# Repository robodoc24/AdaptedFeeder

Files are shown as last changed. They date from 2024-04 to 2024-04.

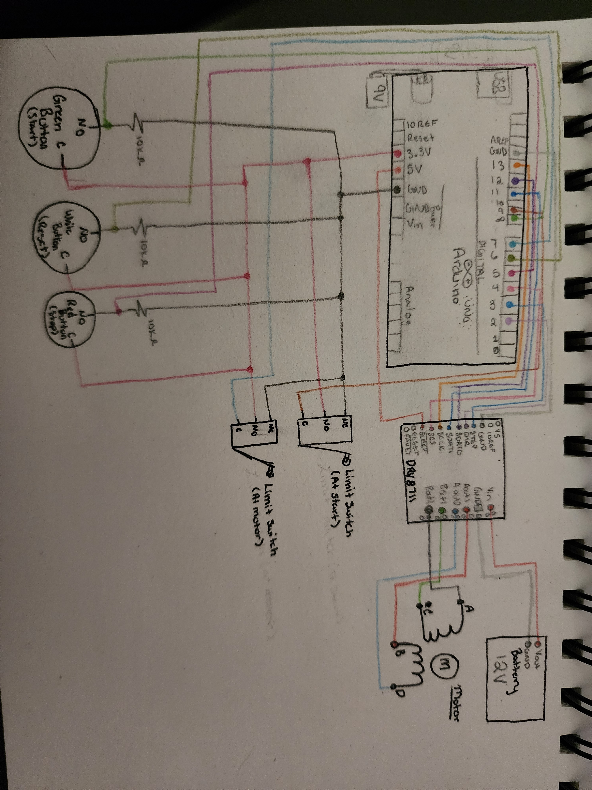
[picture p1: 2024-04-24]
CircuitLayedOut.jpg

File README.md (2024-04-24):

# AdaptedFeeder
The Adapter Feeder is a medical device that is designed to empower individuals facing disabilities such as uncontrollable limb spasms or weakness in the arms, which can hinder independent feeding. This medical device provides essential support by enabling individuals with disabilities to self-feed, reducing their dependence on others. 

Read the user manual for instruction.
There is also a trouble shooting guide in the User Manual.

All files needed to create the device are uploaded here.

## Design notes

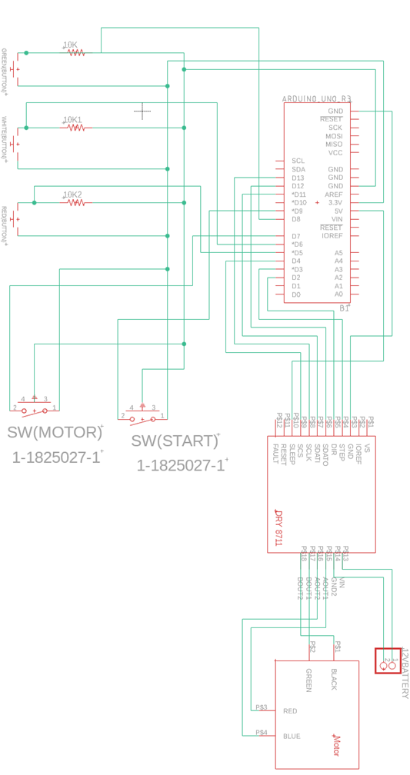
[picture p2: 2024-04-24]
Fusion.png

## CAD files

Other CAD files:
Adaptive Feeder v5.f3z

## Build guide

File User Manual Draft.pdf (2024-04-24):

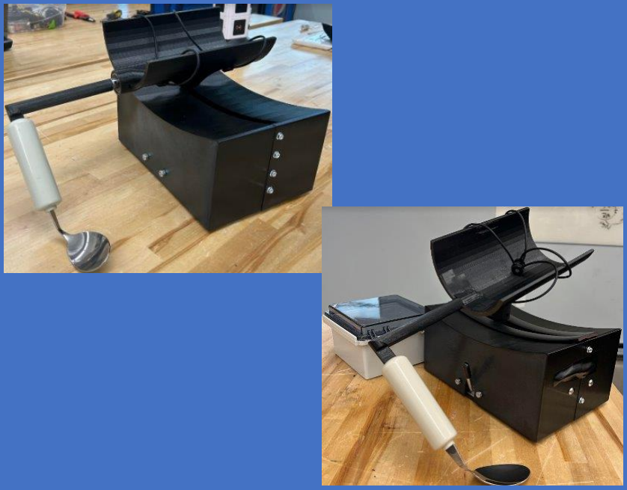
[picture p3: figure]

# ADAPTIVE FEEDER

Our adaptive feeder: a tool for independence, dignity, and empowerment. Let's redefine possibility, one invention at a time.

Grand Canyon
University Capstone

## Table of Contents

# Introduction

## The Adaptive Feeder is a device used to empower individuals with

## disabilities to gain independence in feeding themselves. With its

## intuitive design and helpful features, it serves as a reliable guide to

support users in mastering the art of self-feeding.

# Overview

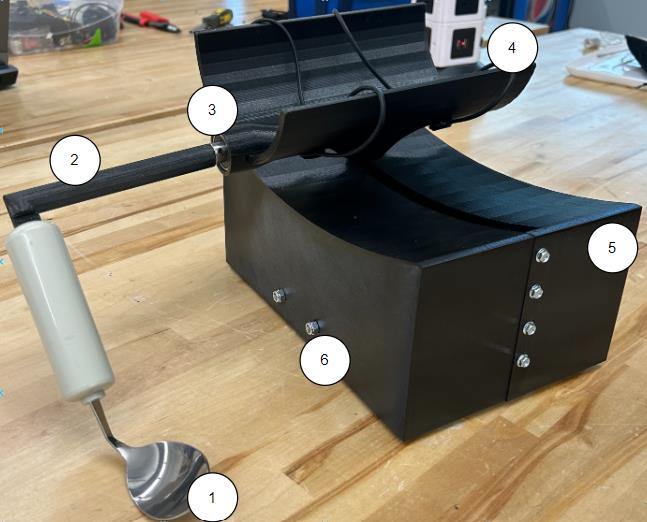
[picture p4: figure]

1. Spoon | 3. Bearing
2. Handlebar | 4. Arm Holder
5. Base | 6. Panavise (Inside Base)

# Materials list

Materials Needed | Quantity | Cost Total ($) | Vendor & Link
Lead Screw and Brass Nut | 1 | $26.97 | Amazon (https://www.amazon.com/QWORK-300mm-Thread-Starts-Printer/dp/B0C2VLY8VH?s=industrial)
Pololu High-Power Stepper Motor Driver 36v4 | 1 | $24.00 | Pololu (https://www.pololu.com/product/3730)
Stepper Motor: Bipolar, 200 Steps/Rev, 57×76mm, 3.2V, 2.8 A/Phase | 1 | $73.37 | Pololu (https://www.pololu.com/product/1478/pictures)
Motor Shaft Coupler | 2 | $12.99 | Amazon (https://www.amazon.com/6-35mm-8mm-Flexible-Coupling-6-35x8mm/dp/B00V84QS2Q?s=hi)
KBT 12V 2400mAh Rechargeable Li-ion Battery | 2 | $22.99 | Amazon (https://www.amazon.com/KBT-2400mAh-Rechargeable-Replacement-Compatible/dp/B0C241NS29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)
9V Battery | 1 | $7.10 | Amazon (https://www.amazon.com/Energizer-Alkaline-General-Purpose-Battery/dp/B00003IE4E)
Certified Food Grade PETG 3D Printer Filament Roll | 2 | $41.61 | Amazon (https://www.amazon.com/Certified-Food-Grade-Printer-Filament/dp/B0BTLNRRN4)
ELEGOO UNO Project Super Starter | 1 | $38.80 | Amazon (https://www.amazon.com/ELEGOO-Project-Tutorial-Controller-Projects/dp/B01D8KOZF4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)
Self-Alignment Bearing | 1 | $9.69 | Amazon (https://www.amazon.com/TAODAN-Silver-Pillow-Bearing-Self-Alignment/dp/B0CHYDYWSP?hvadid=675616684759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)
Adaptive Spoon | 1 | $6.95 | Amazon (https://www.amazon.com/Rehabilitation-Advantage-Teaspoon-Adaptive-Built-up/dp/B07BXFJ8ZV)
Vive Foam Tubing | 1 | $16.14 | Amazon (https://www.amazon.com/Vive-Foam-Tubing-Pack-Dexterity/dp/B01MXVPY53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)
PANAVISE 380 Vacuum Base | 1 | $61.42 | Amazon (https://www.amazon.com/Panavise-8106-PanaVise-Vacuum-Base/dp/B0002BC294?hvadid=312381485501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)
12 Pack 8/32 Inch M4 Threaded Rod with Hex Nuts 12 Pcs M4 Stainless Steel Threads Studs Rods 12 Pcs M4 Stainless Steel Fully Threaded Hex Nuts for Beaded Garden Stake Rods (8 Inch) | 1 | $10.76 | Amazon (https://www.amazon.com/gp/aw/d/B0BLSJX1KX/?aaxitk=236423587a5ec7b18561ca52c3eb3b81&hsa_cr_id=0)
Push Buttons | 3 | $18.88 | Amazon (https://www.amazon.com/dp/B01MSNXLN0?psc=1&ref=ppx_yo2ov_dt_b_product_details)
Limit Switches | 2 | $5.99 | Amazon (https://www.amazon.com/HiLetgo-KW12-3-Roller-Switch-Normally/dp/B07X142VGC?sp_csd=d2lkZ2V0TmFtZT1zcF9hdGY)
Rubber Stripping Roll | 1 | $13.99 | Amazon (https://www.amazon.com/s?k=rubber+striping)
Electrical Waterproof Box | 1 | $20.99 | Amazon (https://www.amazon.com/dp/B0CHHJ49QN?ref=ppx_yo2ov_dt_b_product_details&th=1)
Self-Tapping Hex Screws Pack | 1 | $9.99 | Amazon (https://www.amazon.com/Available-Washer-Drilling-Tapping-Stainless/dp/B08HSTSLQ4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)
Wire Nuts Pack | 1 | $8.97 | Amazon (https://www.amazon.com/Electrical-Wire-Connectors-Screw-Terminals/dp/B082KMK6Y9?sp_csd=d2lkZ2V0TmFtZT1zcF9hdGY)
Magnet Straps | 4 | $14.99 | Amazon (https://www.amazon.com/Magnetic-Organizer-FGSAEOR-Management-Organizing/dp/B0B2DTD4QK)
Speaker Wire Spool | 1 | $8.99 | Amazon (https://www.amazon.com/InstallGear-Gauge-30ft-Speaker-Cable/dp/B078YYXDWP)
Electrical Tape | 1 | $4.98 | Amazon (https://www.amazon.com/Scotch-Super-33-Electrical-carton/dp/B0000AZ9HG)
Total (Electric) | | $460.56
Total (Mechanical-Underlined) | | $155.86

# Health and Safety

## - Make sure to read all the instructions before building the device and make sure to use the CAD/code files attached in the links section. If done incorrectly the device may not work

properly and could cause harm.

## - The adaptive feeder should not be used without someone

supervising in case of choking or something going wrong.

## - People with uncontrolled movements should not use metal

spoons on the device, instead use plastic ones.
- Make sure to not run device if a wire is exposed.
- Make sure to have a fully or half charged battery.

## - Do not touch any exposed electrical components when the

power is on.

## - Before use make sure the base is fully secured to the table with the Pana-Vise - Ensure the device was reassembled correctly and nothing is to

lose.

## - Do a routine check up on all components every two or three

weeks.
- Make sure to wipe and clean all parts before every meal.

# Adaptations

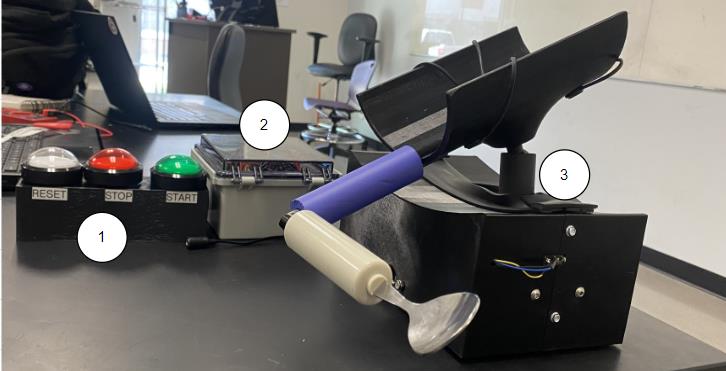
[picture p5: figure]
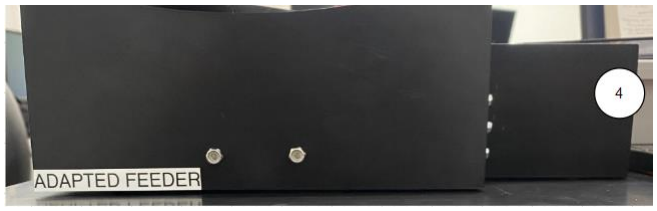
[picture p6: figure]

## 1. A button box with buttons can be added to make the motorized version of this device 2. An electrical box needs to be added to maintain all the wires

safe for the motorized version.

## 3. The joint can at the spoon holder can be removed and a joint can be added on the base for the motorized version 4. The motor and screw rod can be removed and the adaptive

could be used mechanically.

## 5. The motor and screw rod can be removed and the adaptive

could be used mechanically.

## 6. The motor case needs to be added to keep the motor safe from

any food and make it the motorized version.

# Quick Set up with motor

1.

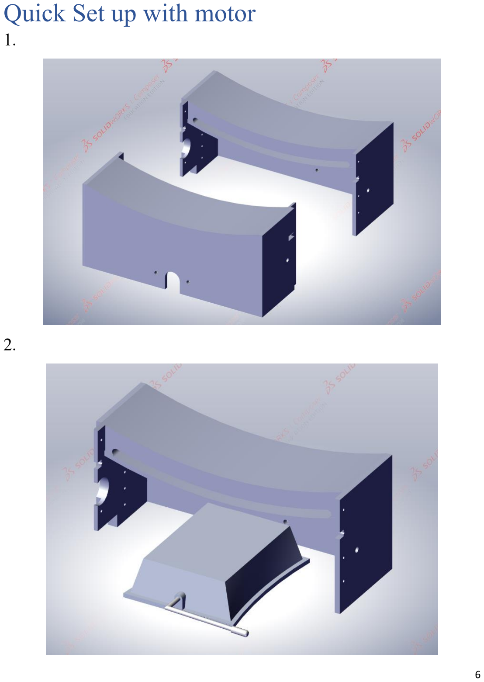
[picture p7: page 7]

2.

3

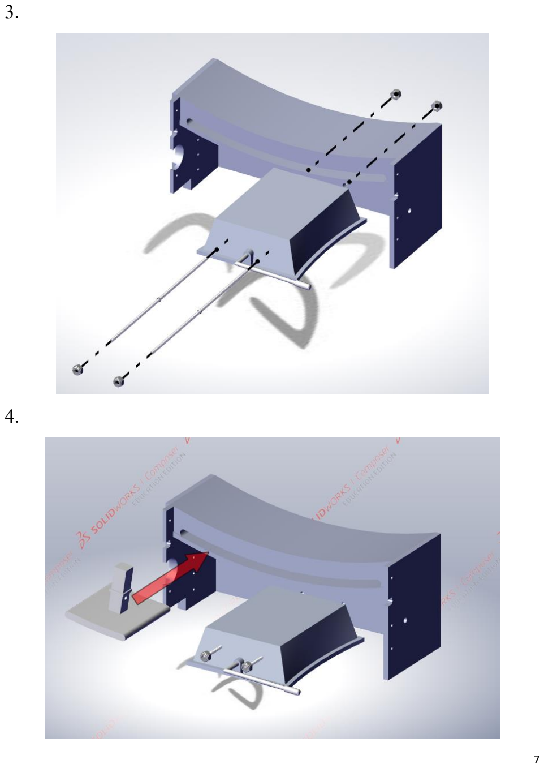
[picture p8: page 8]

4.

5.

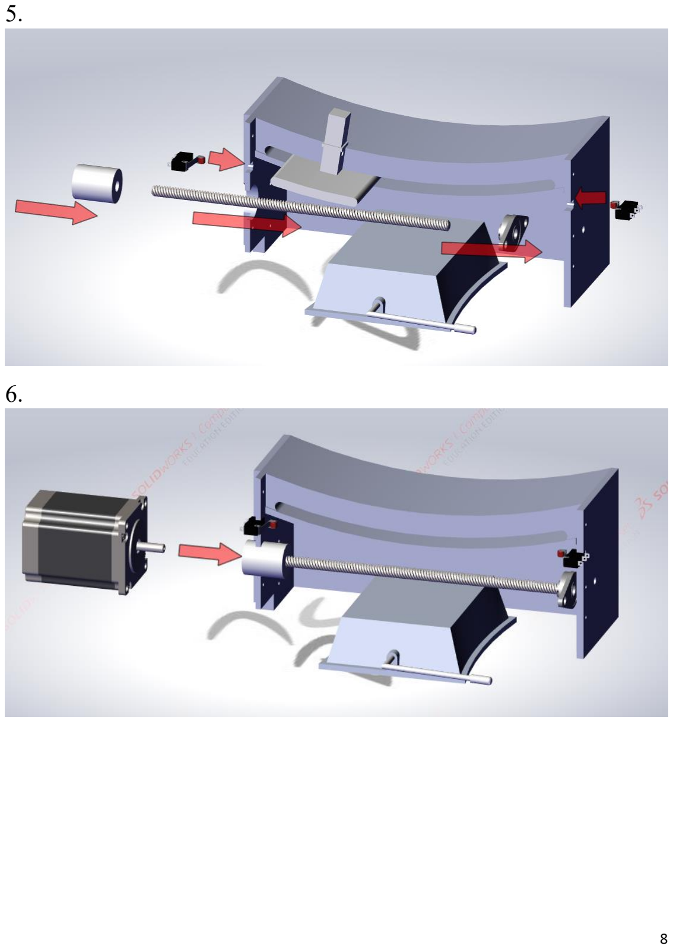
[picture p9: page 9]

6.

7.

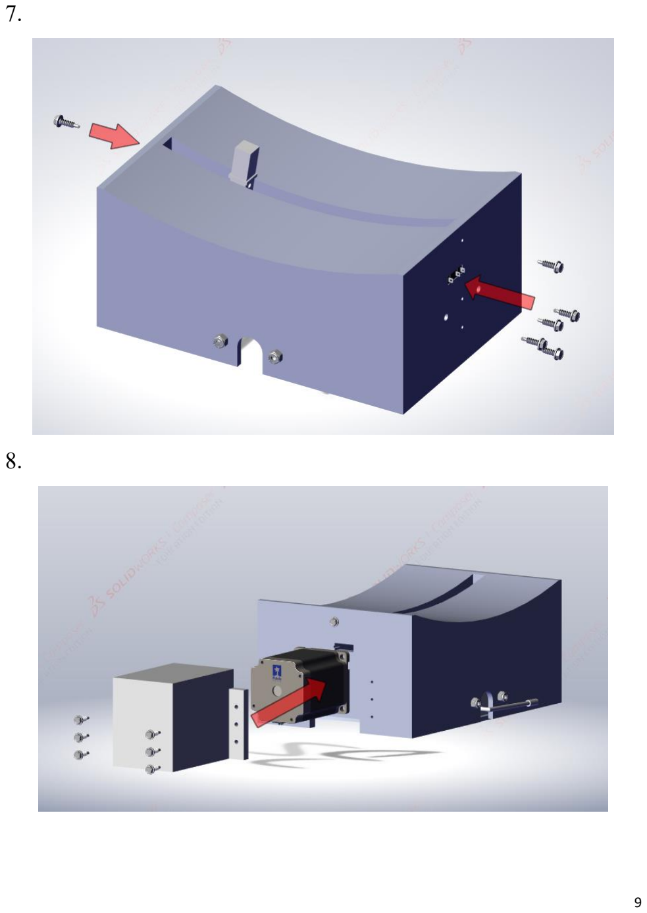
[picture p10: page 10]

8.

9.

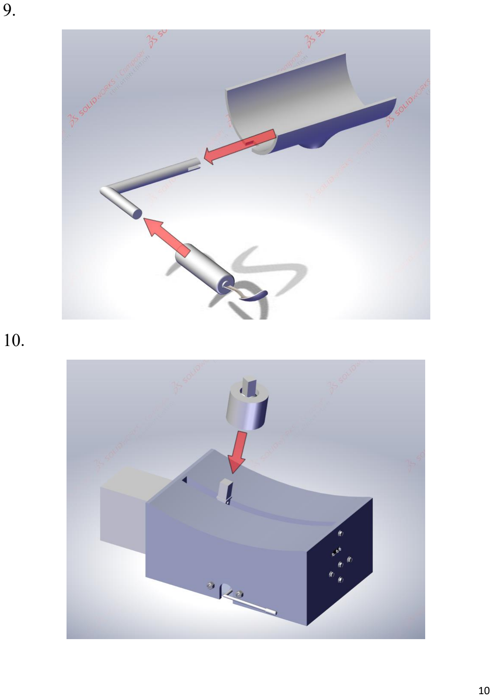
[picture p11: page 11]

10.

11.

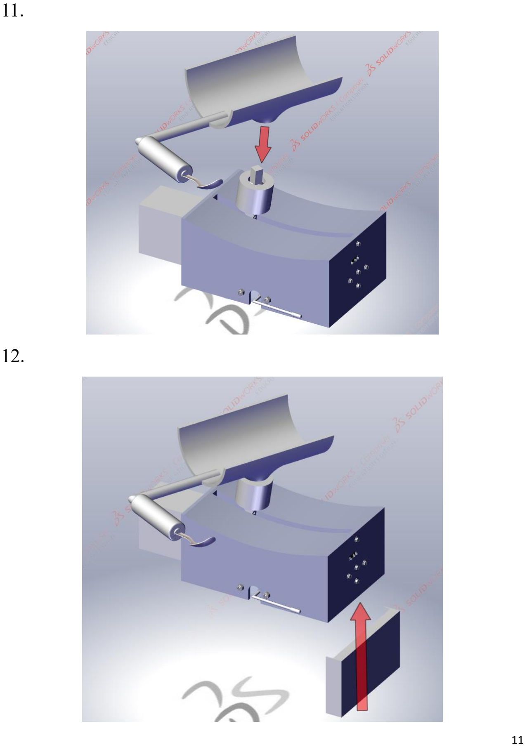
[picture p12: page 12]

12.

13.

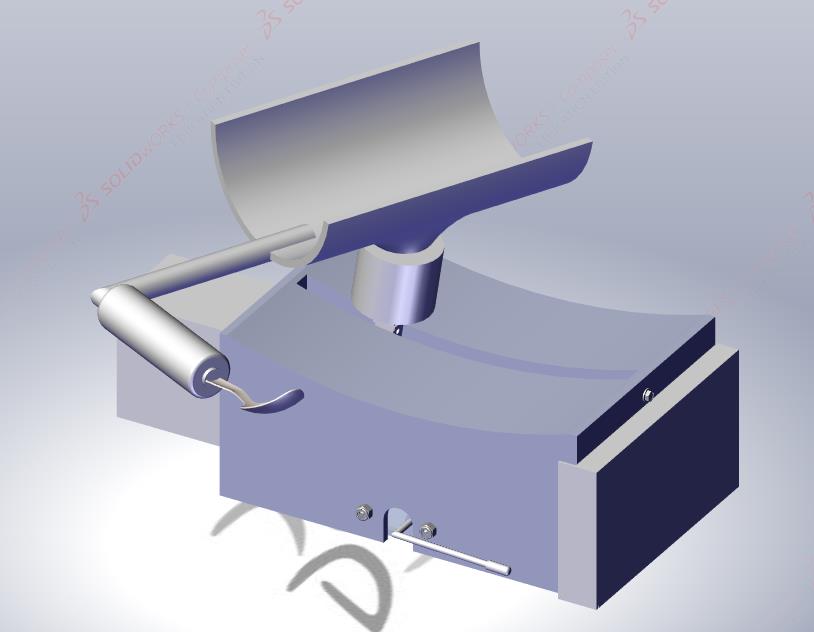
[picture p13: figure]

# Quick Set Up Without Motor

## Reference these steps 1, 2, 3, 4, 7, 9, 10 and 11 from Quick Motor

Set Up.

# Electrical Diagram how to build

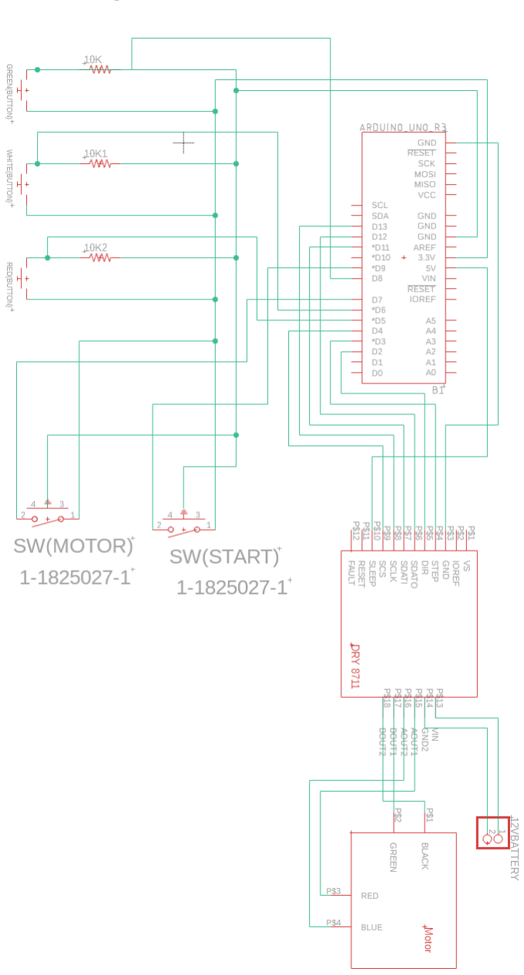
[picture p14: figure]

# How to assemble

## Mechanical Design: Assemble into 3 pieces Place part 3 on part 1 at the flat surface. Then place part 1 on part 4 the slider. To add more support to the handle on part 1 add part 2 to

the area with the round surface.

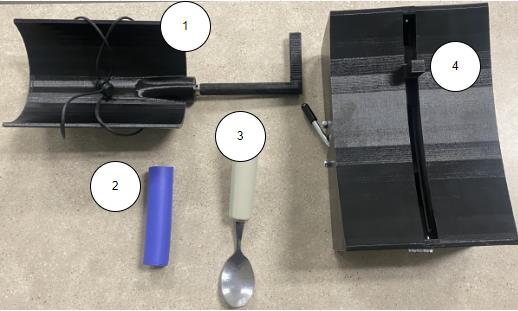
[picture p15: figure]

## For further detail watch the YouTube video called “Mechanical Assemble”

## Motorized Design: Assemble into 3 pieces Place part 2 on part 4 where the square indent is. Place part 1 on part two where there is a flat surface. Then place all parts onto part 1 the base on part 5. To add a better grip place part three on part 2 around

the round part.

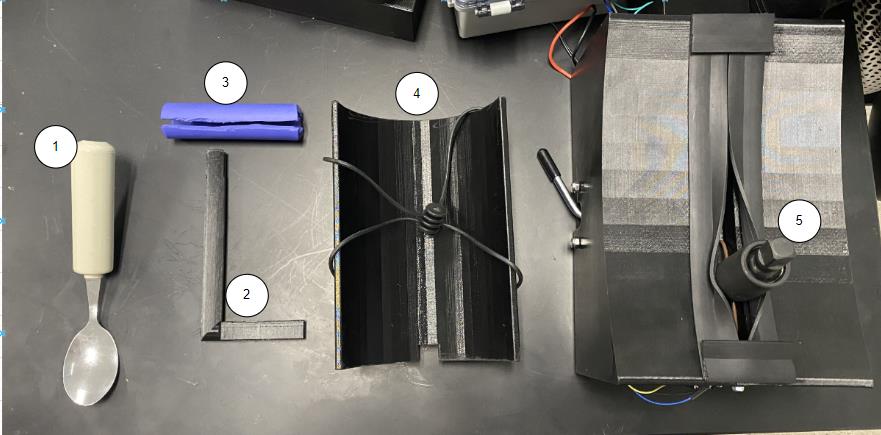
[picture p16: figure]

## For further detail watch the YouTube video called “Motorized Assembled”

# How to dissemble for easy storage

## Mechanical Desing: Disassemble into 3 pieces

## Remove part 1 from part 4 the slider. Then remove part 3 and 2 for

easier storage and cleaning.

## For further detail watch the YouTube video called “Mechanical Disassemble”

## Motorized Design: Disassemble into 5 pieces

## Remove part 1 by pulling it off part two. Next pull part 2 from part

4 and remove part 3. Once the smaller compartments are off,

## remove the arm holder part 4 from part 5. Removing all parts creates easier access to clean and store. Everything now can be stored in a

cabinet.

## For further detail watch the YouTube video called “Motorized Disassemble”

# Maintenance and Cleaning

## How to clean spoon Remove the spoon from the adaptive feeder by pulling it off. Put

spoon on the dishwasher or clean by hand with soap and water.

## How to clean the arm support To clean the arm support remove it from the base by the ball joint

and use soap and water to clean.

## How to clean the base and other components To clean the outside of the base, use a wet towel with disinfectant spray. If food falls inside the track, make sure to take apart the base by removing the screws and wiping the inside down. Make sure to

also wipe down the lead screw.

## How to prevent the lead screw from rusting To help the lead screw last longer grease can be applied. Add a bit of grease on the lead screw and run the motor to ensure the entire lead screw is covered. Lightly remove extra grease if any. If the lead

screw needs cleaning reapply grease.

## How to clean electrical components

Do not use any disinfectant or water to clean electrical components.

## Use a dry paper towel and wipe the electronic parts. If it is wet do not turn it on until it is completely dry. Make sure to test the adaptive feeder on its own first to make sure everything works

correctly. If everything moves correctly it can be used as normal.

## Chip and motor regular checkup

Check the wires for any pinching or the soldering for dulling, rough,

## or cracking in appearance to ensure the soldering of the electrical

components are still at max efficiency.

# Trouble Shooting

Problem | Possible Problem | Solution | Did it fix the problem?
For any problem start at the code, its designed to help isolate a problem. | Have the serial monitor open connected to the Arduino. | Read the serial motor for hits on any buttons that are not working and follow comments for helpful hints. | YES/NO
Not moving and no sound | A wire may have come undone | Check Wires | YES/NO
| Is it on? | Turn on power | YES/NO
Moved but stopped at motor (after hitting green button) | Did the power get turned off? | Turn on the power | YES/NO
| Are any wires loose? | Check wires plug in any loose wires | YES/NO
Started to move and stopped or not moving with a grinding sound | Is the bearing tight? | Tighten the bearing | YES/NO
| Is the coupler tight? | Check the coupler and tighten | YES/NO
| Is the lead screw too long? | Shorten the lead screw and make sure it has smooth end | YES/NO
Motor moves to slow | Check the code | Follow the comments to change the speed | YES/NO

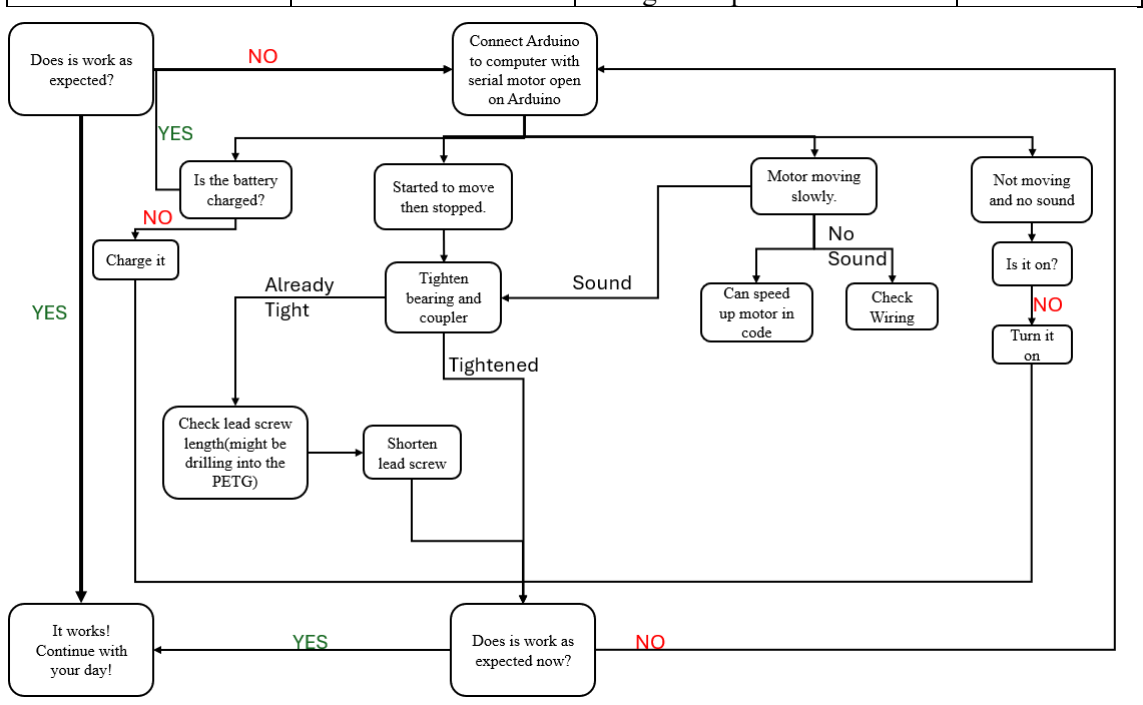
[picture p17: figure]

# File Links

## GitHub Link with all the SolidWorks File and Code: https://github.com/robodoc24/AdaptedFeeder

## YouTube channel: https://www.youtube.com/@AdaptiveFeeder

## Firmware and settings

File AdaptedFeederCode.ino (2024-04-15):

// This is the code for the adapted feeder to run with having the full set up of electronics 
// as shown in the github.

// Before using this example, be sure to change the setCurrentMilliamps36v4 line
// to have an appropriate current limit for your system. For the adapted if using the 
// stepper driver and motor suggested in the github the current is 2800.

#include <SPI.h>
#include <HighPowerStepperDriver.h> //You may need to download the library to use. 
//Library is called HighPowerStepperDriver by Pololu

const uint8_t CSPin = 4; //This is for the Stepper Driver
const int buttonPin = 8; //This is where your start button is connected and defined
const int switchBeginning = 9; //This is the limit switch at the beginning
const int switchAtMotor = 7; //This is the limit switch at the motor
const int stopButton = 5; //Stop button
const int resetButton = 6; //Reset button back to start position

//The intial states of all the buttons
int buttonState = 0;  //Should be Zero
int switchBeginningState = 0; //Should be Zero
int switchAtMotorState = 0; //Should be Zero
int stopButtonState = 0; //Should be Zero
int resetState = 0; //Should be Zero
int direction = 1; //Negative moves backwards while positive moves forward
bool startButton = false;

const uint16_t StepPeriodUs = 10;// This period is the length of the delay between steps, which controls the
// stepper motor's speed.  You can increase the delay to make the stepper motor
// go slower.  If you decrease the delay, the stepper motor will go faster, but
// there is a limit to how fast it can go before it starts missing steps.

HighPowerStepperDriver sd; //Here are important for the stepper driver

void setup()
{
  Serial.begin(9600); //This is needed for the serial Moniter which is good for debugging
  SPI.begin();
  sd.setChipSelectPin(CSPin);
  pinMode(buttonPin, INPUT);
  delay(500); // Give the driver some time to power up. 
  Serial.print("Finished Delay"); //For debugging
  
  sd.resetSettings(); // Reset the driver to its default settings and clear latched status conditions.
  sd.clearStatus();

    sd.setDecayMode(HPSDDecayMode::AutoMixed);// Select auto mixed decay.  TI's DRV8711 documentation recommends this mode
  // for most applications, and we find that it usually works well.

  
  sd.setCurrentMilliamps36v4(2800);// Set the current limit. You should change the number here to an appropriate
  // value for your particular system if not using the recommend motor and stepper driver

  // Set the number of microsteps that correspond to one full step.
  sd.setStepMode(HPSDStepMode::MicroStep32);

  // Enable the motor outputs.
  sd.enableDriver();
  //sd.setDirection(0);
}

void loop()
{
  //This allows for the buttons to be read without this nothing will happen
  buttonState = digitalRead(buttonPin);
  switchBeginningState = digitalRead(switchBeginning);
  switchAtMotorState = digitalRead(switchAtMotor);
  resetState = digitalRead(resetButton);
  stopButtonState = digitalRead(stopButton);
 
  //Start of the motor state
  //direction(0) goes away from motor
  //direction(1) goes towards motor
  if(stopButtonState == LOW) //If the Stop Button is not pressed so its normal state
  {
    if(startButton == false) //Before Start button is pressed or after whole cycle or after stop button it will return here
     {
      if(switchBeginningState == HIGH)// this is what sets up the motor moving reading where it is at 
      {
        if(buttonState == HIGH)//button hit
        {
          startButton = true;
          direction = -1;
          sd.setDirection(0);
          Serial.println("ButtonPressed"); //Here for debugging
        }
      }
      else if(resetState == HIGH) { //Returns to start position
        startButton = true;
        direction = 0;
        Serial.println("Reset Hit"); //Here for debugging
        sd.setDirection(1);
      }
     }
     else //When the Start Button is pressed
     {
      if(direction < 0)
      {
        if(switchAtMotorState == HIGH) //Move towards the motor point
        {
          direction = 1;
          Serial.println("SwitchAtMotor Switched directions"); //Here for debugging
          Serial.println("Going Back"); //Here for debugging
          sd.setDirection(1);
        }
        else 
        {
          sd.step(); //this moves the motor
          delayMicroseconds(StepPeriodUs); //How fast the motor is moving
        }
      }
      else if(direction == 0) //Return to Start from restart button
      {
        if(switchBeginningState == HIGH){
          direction = -1;
          Serial.println("Resetting"); //Here for debugging
          sd.setDirection(1);
          startButton = false;
        }
        else
        {
          sd.step(); //this moves the motor
          delayMicroseconds(StepPeriodUs); //How fast the motor is moving
        }
      }
      else
      {
        if(switchBeginningState == HIGH) //move towards motor
        {
          startButton= false;
          direction = -1;
          //Serial.print("Stop"); //Here for debugging
          sd.setDirection(0);
          Serial.println("Going Forward"); //Here for debugging
        }
        else 
        {
          sd.step(); //this moves the motor
          delayMicroseconds(StepPeriodUs); //How fast the motor is moving

        }
      }      
    }
  }
  else //If the stop button is pressed
  {
    startButton = false; //this will stop the deviece
    Serial.println("Stop"); //Here for debugging
  }
}

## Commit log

2024-04-24 Circuit Layout in Fusion and Hand-written
2024-04-24 PCB Layout
    [Adaptive Feeder v5.f3z]
